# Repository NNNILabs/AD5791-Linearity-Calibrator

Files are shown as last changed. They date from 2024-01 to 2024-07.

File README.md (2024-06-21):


# AD5791 Linearity Calibrator

<p align="center">
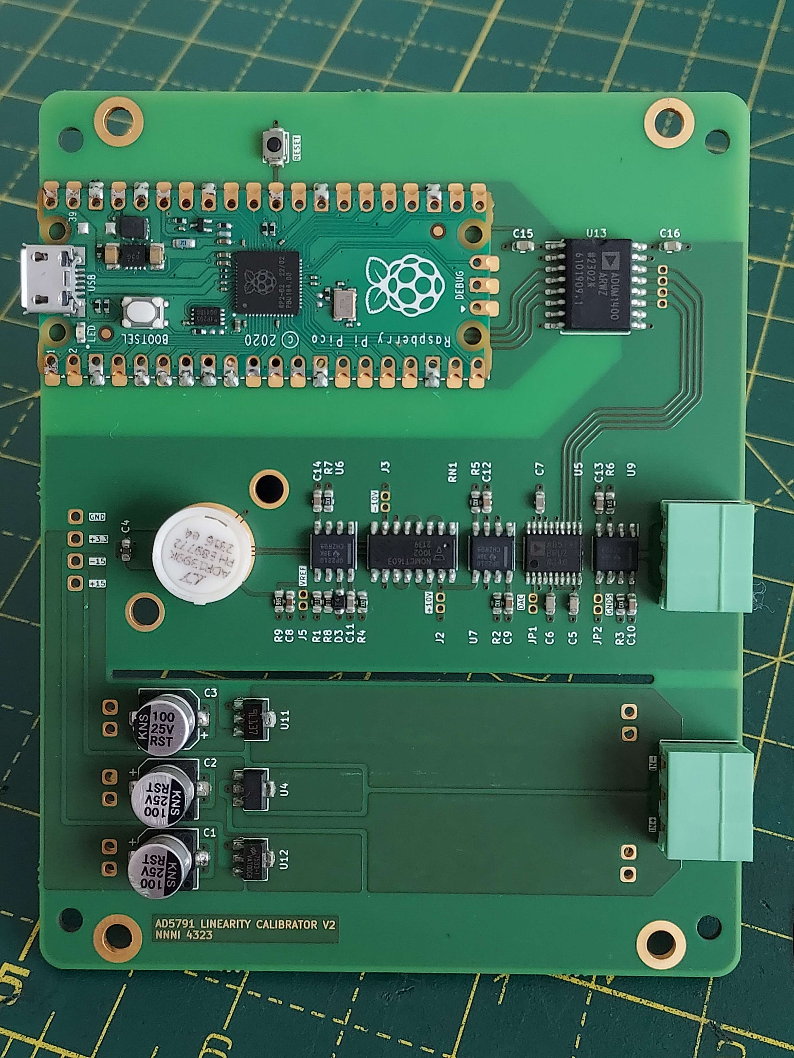
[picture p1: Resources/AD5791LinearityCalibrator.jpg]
  
</p>

## Introduction
Portable voltage, current and resistance standards exist and can be bought for a hole in your pocket, but linearity has exclusively been the domain of high-end bench multimeters. This project contains files for a linearity calibrator based around the AD5791BRUZ 20 bit DAC and a few assisting components. 
## Project Motivation
The gold standard for DMM linearity is the HP/Agilent/Keysight 3458A. This meter costs upwards of several thousand Euros and is out of reach for most people.
While the AD5791 is not even close in terms of absolute linearity, the fact that it can be bought for much less (around 100 Euros) and has decent long-term INL stability (0.19LSB) makes it a good choice for a linearity transfer standard.
## Usage
The C/C++ SDK for the Raspberry Pi Pico can be installed using the one-click installer found [here](https://github.com/raspberrypi/pico-setup/blob/master/pico_setup.sh). The SW folder is opened using 'Pico - Visual Studio Code', and built using the 'gcc-arm-none-eabi' tool. The build file (AD5791LinCal.uf2) can be uploaded to a connected Pico by using upload.bat after suitable configuration (see notes).  

Power is supplied through the 3.5mm terminal block with the labels 'IN+' and 'IN-'. +/-18V is an ideal nominal supply. The DAC board is connected to a computer through the Raspberry Pi Pico controller's micro USB port. Communicating with the DAC is possible through any serial terminal. The binary code representing the desired output voltage is typed in, and the enter key is pressed to update the DAC output. The buffered DAC output is available on the 3.5mm terminal block with the labels 'OUT+' and 'OUT-'. Raw DAC output is available on the 'DAC' test point.  
  
The DAC's transfer function is as follows:
```math
V_{OUT} = \frac{(V_{REFP} - V_{REFN}) D}{2^{20} - 1} + V_{REFN}
```
Where:  
V<sub>OUT</sub> is the desired output voltage  
V<sub>REFP</sub> is the positive reference voltage (in this case approximately 10.5V)  
V<sub>REFN</sub> is the negative reference voltage (in this case approximately -10.5V)  
D is the integer digital code (0 to 1048575)  
  
For example, 0 would result in V<sub>REFN</sub> on the output, 524288 would result in ~0V, and 1048575 would result in V<sub>REFP</sub>. Each step is therefore approximately 20uV.

### Linearity
An example of the AD5791 DAC board was constructed and linearity was measured against a HP3458A DMM. Pre-endpoint fit was used to process the raw data from the DMM to provide a linearity chart. The starting and ending points of the linearity run (in this case, 0 and 1032192) were measured first, and used to pre-calculate m and c values that are applied to the complete run that follows. This provides an indication of drift, and if its effect on the run was larger than the peak non-linearity, in which case the run can be discarded. In this example, the drift across all five runs was around 0.3ppm, corresponding to 3uV.

<p align="center">
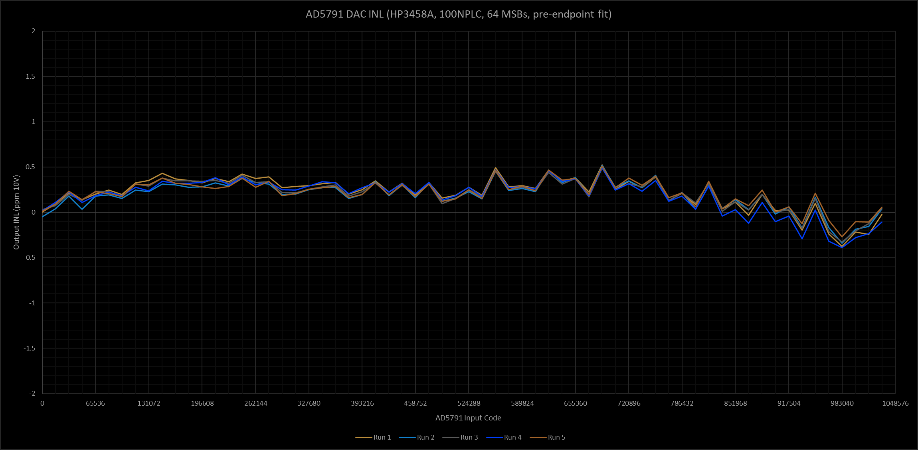
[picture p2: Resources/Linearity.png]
  
</p>

## List of Files
- Hardware: KiCAD schematic and PCB files, GERBER files, BOM
- Software: C/C++ code for the Raspberry Pi Pico, .uf2 file for direct upload, upload.bat upload assistant
- Resources: Images, AD5791 datasheet and ISSCC paper mirror
## Application Examples
### Determining Linearity of a DMM
Integral Non-Linearity (INL) describes how the input/output transfer function of a multimeter differs from the ideal straight line. Test methodology involves connecting a voltage source with a known linearity to the meter, and measuring meter readings at various points. Since the meter and source gains and offsets are not guaranteed to be the same, the source gain and offset has to be "normalized" to the meter gain and offset through a simple linear endpoint-fit method. Although some information at the endpoints is lost, it is most often the "shape" of the INL curve that is of interest. The data could possibly be used to derive a transfer function to further increase DAC/ADC linearity.
### Stable, Precise Voltage Source
Given the high resolution of the AD5791 (20 bits), fine voltage steps of 20uV can be achieved. This facilitates experiments that need ultrafine voltage steps. In some cases, the DAC, with its 1us settling time, can be used to generate precision waveforms through additional code modification (Wave table -> DMA -> PIO). 
## Notes
- By initializing GPIO 23 as an output and setting it high, the Raspberry Pi Pico's internal SMPS switches to PWM mode, where radiated EMI and output ripple is lower.
- PCB template is a modified version of [Mark's Protocard template](https://github.com/macaba/Nuts/tree/main/kicad-templates).
- [upload.bat](https://github.com/NNNILabs/AD5791-Linearity-Calibrator/blob/main/SW/upload.bat) was created by Utsuho, and faciliates hands-free upload to the Pico. The COM port the Pico is connected to and the drive letter are entered in lines 7 and 11 respectively. After the software is built, upload.bat is run from the terminal by doing '.\upload.bat' on Windows. The Pico enters boot mode and the .uf2 from the build folder is automatically uploaded. Make sure the COM port is not being accessed by other programs.
## Links
- [AD5791 Datasheet](https://github.com/NNNILabs/AD5791-Linearity-Calibrator/blob/main/Resources/AD5791%20Datasheet.pdf)
- [ISSCC Paper](https://github.com/NNNILabs/AD5791-Linearity-Calibrator/blob/main/Resources/AD5791%20ISSCC.pdf)
- [Reference voltage cap](https://www.printables.com/model/746207-voltage-reference-cap)

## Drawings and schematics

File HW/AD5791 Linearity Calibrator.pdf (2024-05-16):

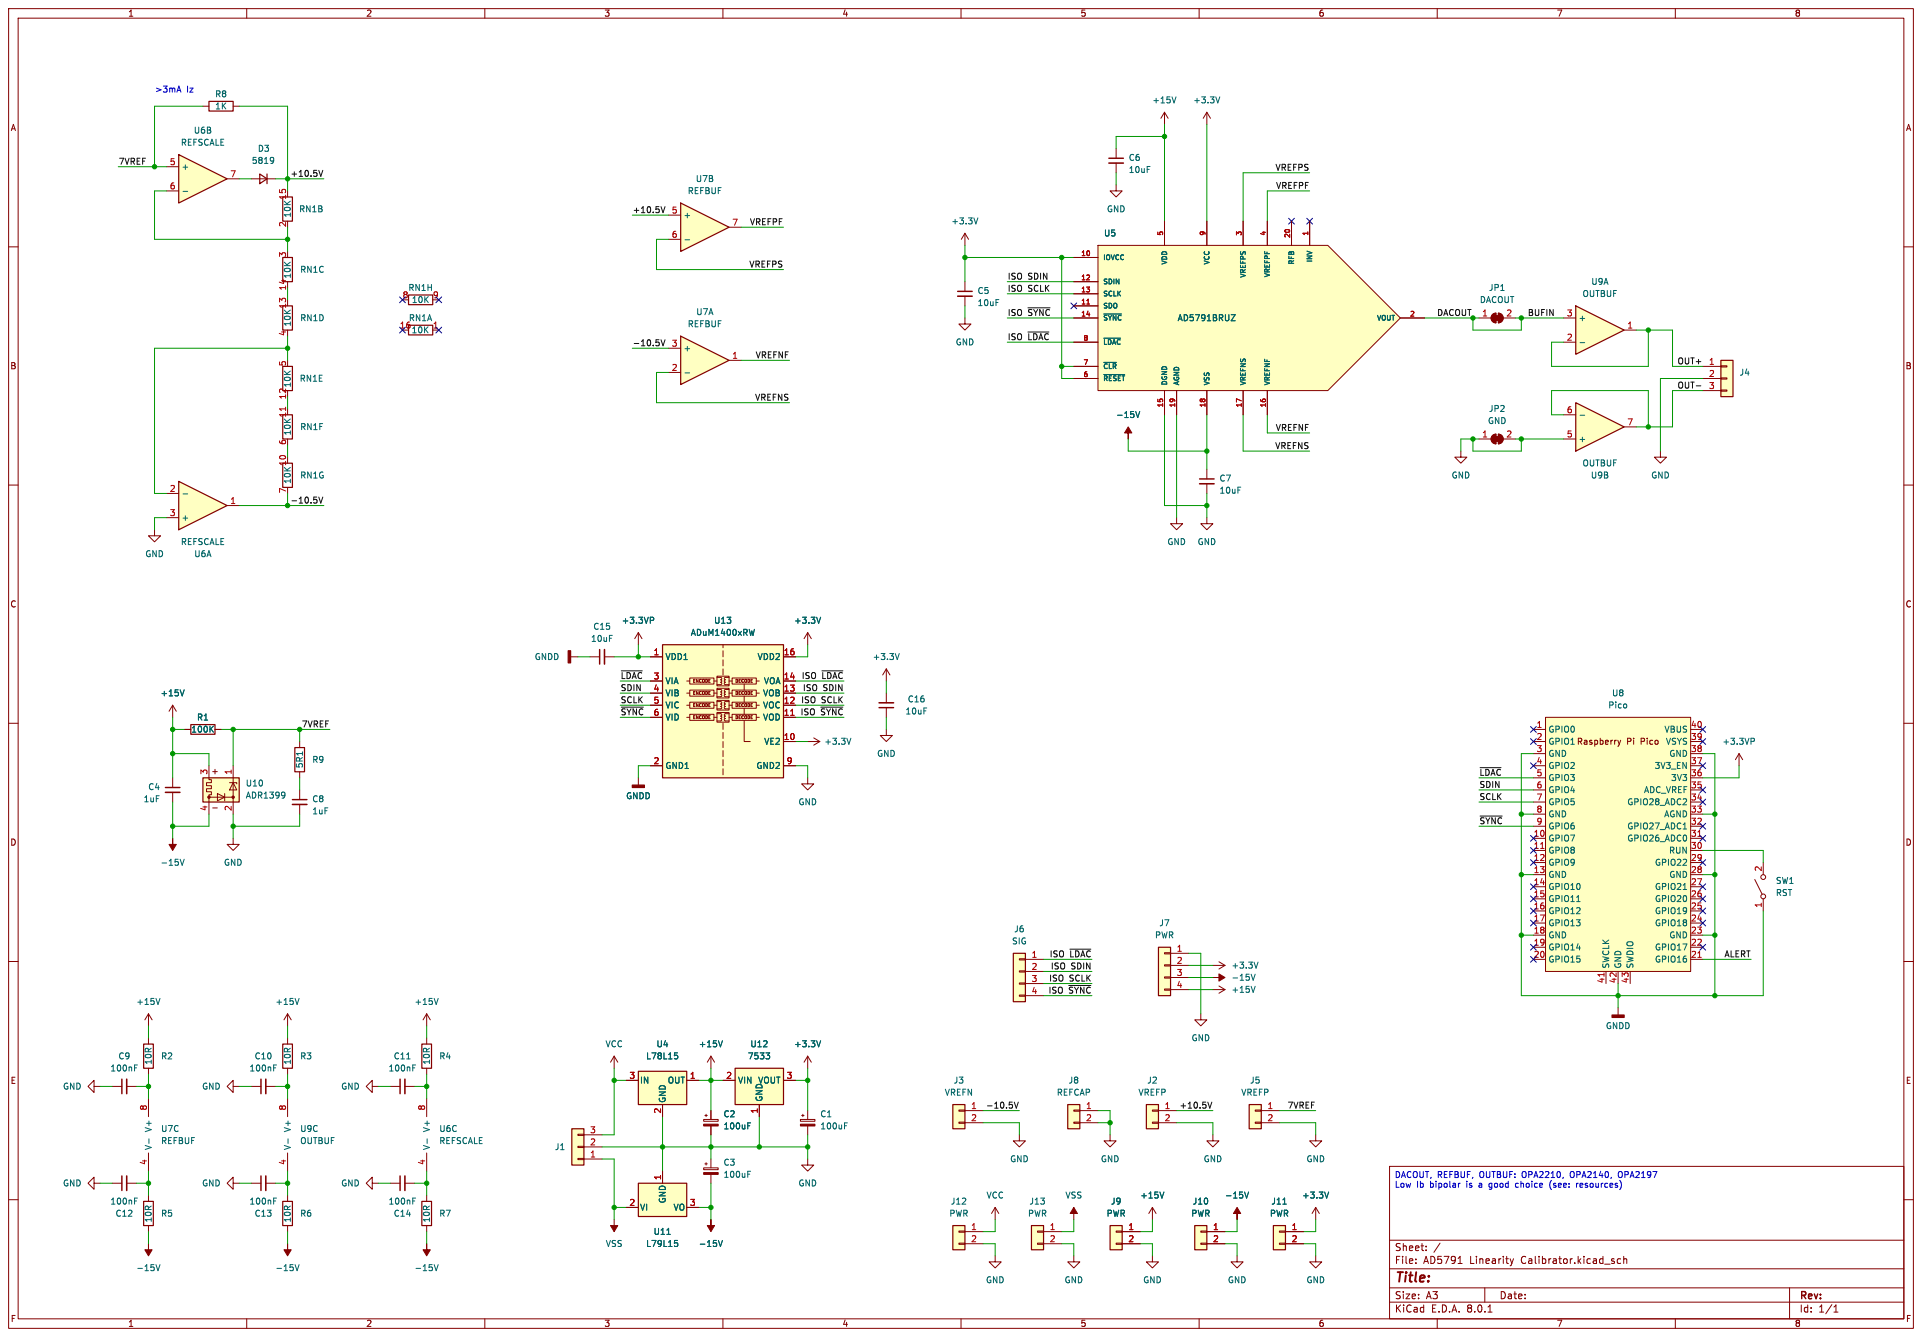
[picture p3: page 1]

5 ~{RESET} 6 ~{CLR} 7 ~{LDAC} 8 VCC U5 9 AD5791BRUZ

5 ~{RESET} 6 ~{CLR} 7 ~{LDAC} 8 VCC

DECODE DECODE

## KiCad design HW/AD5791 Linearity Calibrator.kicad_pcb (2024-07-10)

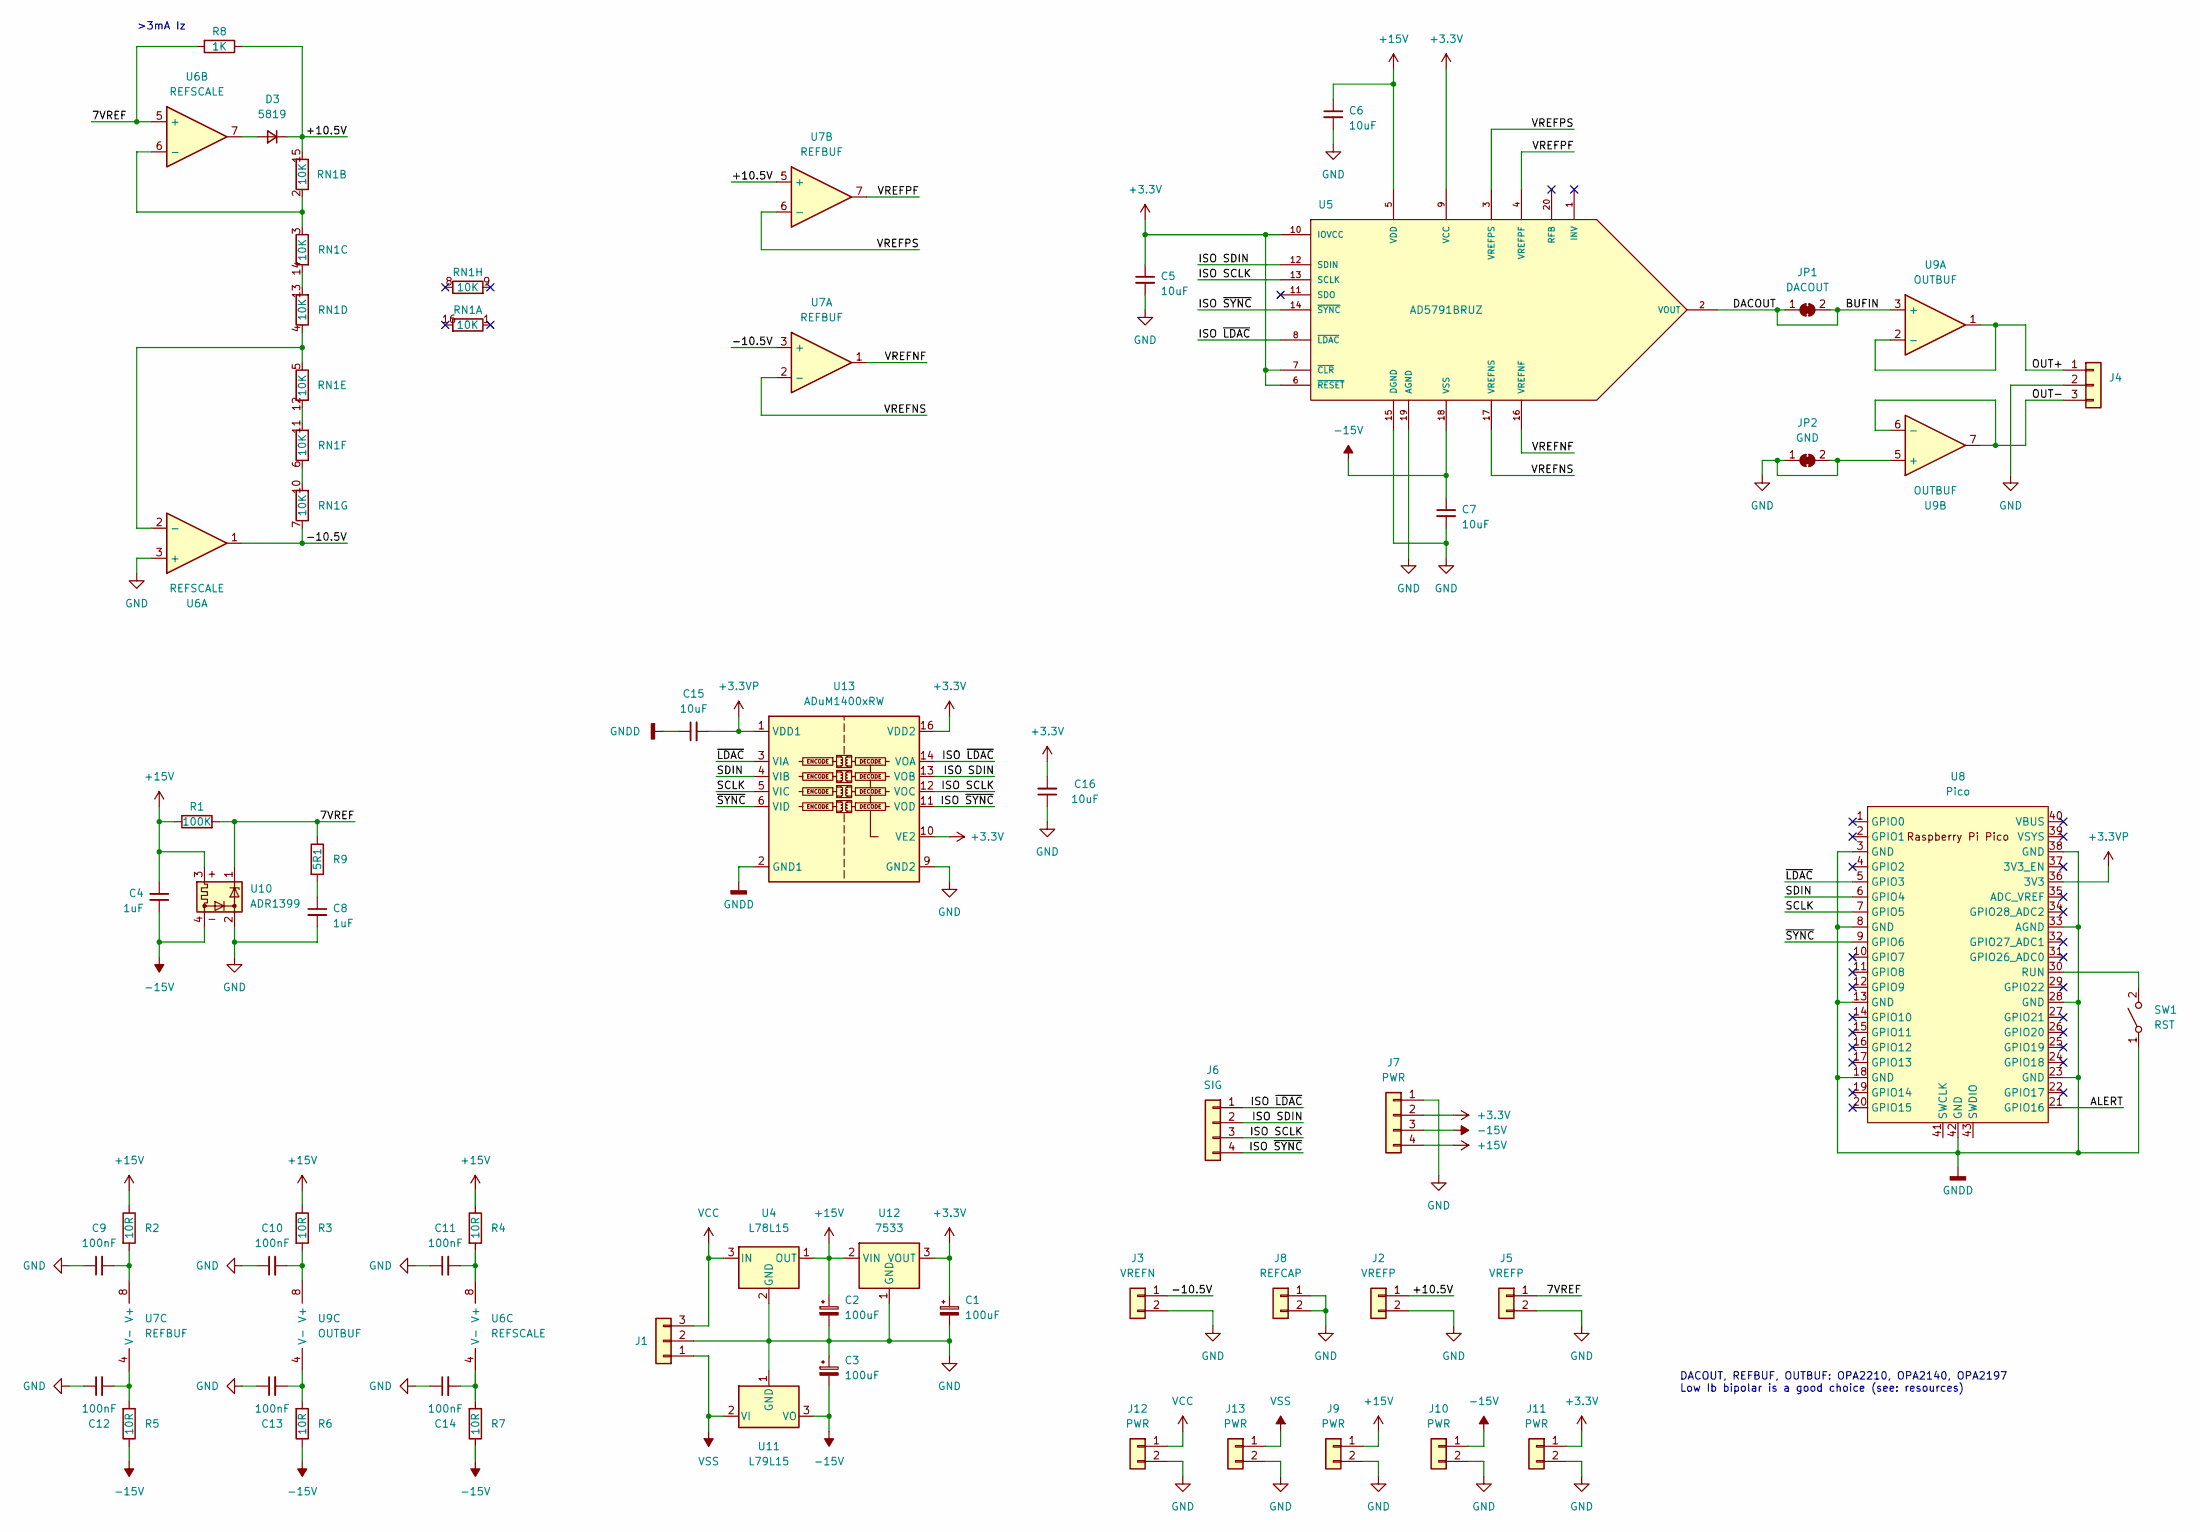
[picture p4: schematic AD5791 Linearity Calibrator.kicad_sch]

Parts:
C1, C2, C3: 100uF; CP_Elec_6.3x5.4
C4, C8: 1uF; C_0603_1608Metric
C5, C6, C7: 10uF; C_0603_1608Metric
C9, C10, C11, C12, C13, C14: 100nF; C_0603_1608Metric
C15, C16: 10uF; R_0603_1608Metric
D3: 5819; R_0603_1608Metric_Pad0.98x0.95mm_HandSolder
J1, J4: CTB93HD3
J2, J5: VREFP; PinHeader_1x02_P1.27mm_Vertical
J3: VREFN; PinHeader_1x02_P1.27mm_Vertical
J6: SIG; PinHeader_1x04_P1.27mm_Vertical
J7: PWR; PinHeader_1x04_P2.54mm_Vertical
J8: REFCAP; PinHeader_1x02_P1.27mm_Vertical
J9, J10, J11, J12, J13: PWR; PinHeader_1x02_P2.54mm_Vertical
JP1: DACOUT; PinHeader_1x02_P1.27mm_Vertical
JP2: GND; PinHeader_1x02_P1.27mm_Vertical
R1: 100K; R_0603_1608Metric
R2, R3, R4, R5, R6, R7: 10R; R_0603_1608Metric
R8: 1K; R_0603_1608Metric
R9: 5R1; R_0603_1608Metric
RN1: 10K; SOIC-16_3.9x9.9mm_P1.27mm
SW1: RST; SW_SPST_B3U-1000P
U4: L78L15; SOT-89-3
U5: AD5791BRUZ; SOP65P640X120-20N; MPN AD5791BRUZ
U6: REFSCALE; SOIC-8_3.9x4.9mm_P1.27mm
U7: REFBUF; SOIC-8_3.9x4.9mm_P1.27mm
U8: Pico; RPi_Pico_SMD_TH
U9: OUTBUF; SOIC-8_3.9x4.9mm_P1.27mm
U10: ADR1399; Analog_TO-46-4_ThermalShield
U11: L79L15; SOT-89-3
U12: 7533; SOT-89-3
U13: ADuM1400xRW; SOIC-16W_7.5x10.3mm_P1.27mm

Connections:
+3.3V: C1.1, C5.1, C16.2, J7.2, J11.1, U5.6 (~RESET), U5.7 (~CLR), U5.9 (VCC), U5.10 (IOVCC), U12.3 (VOUT), U13.10 (VE2), U13.16 (VDD2)
+3.3VP: C15.2, U8.36 (3V3), U13.1 (VDD1)
+15V: C2.1, C4.1, C6.1, J7.4, J9.1, R1.1, R2.1, R3.1, R4.1, U4.1 (OUT), U5.5 (VDD), U10.3, U12.2 (VIN)
-15V: C3.2, C4.2, C7.1, J7.3, J10.1, R5.1, R6.1, R7.1, U5.18 (VSS), U10.4, U11.3 (VO)
/7VREF: J5.1, R1.2, R8.2, R9.1, U6.5 (+), U10.1
/+10.5V: D3.1 (K), J2.1, R8.1, RN1.15 (R2.2), U7.5 (+)
/-10.5V: J3.1, RN1.7 (R7.1), U6.1, U7.3 (+)
/ALERT: U8.21 (GPIO16)
/BUFIN: JP1.1 (A), JP1.2 (B), U5.2 (VOUT), U9.3 (+)
/ISO SCLK: J6.3, U5.13 (SCLK), U13.12 (VOC)
/ISO SDIN: J6.2, U5.12 (SDIN), U13.13 (VOB)
/ISO ~LDAC: J6.1, U5.8 (~LDAC), U13.14 (VOA)
/ISO ~SYNC: J6.4, U5.14 (~SYNC), U13.11 (VOD)
/OUT+: J4.1, U9.1, U9.2 (-)
/OUT-: J4.3, U9.6 (-), U9.7
/SCLK: U8.7 (GPIO5), U13.5 (VIC)
/SDIN: U8.6 (GPIO4), U13.4 (VIB)
/VREFNF: U5.16 (VREFNF), U7.1
/VREFNS: U5.17 (VREFNS), U7.2 (-)
/VREFPF: U5.4 (VREFPF), U7.7
/VREFPS: U5.3 (VREFPS), U7.6 (-)
/~LDAC: U8.5 (GPIO3), U13.3 (VIA)
/~SYNC: U8.9 (GPIO6), U13.6 (VID)
GND: C1.2, C2.2, C3.1, C5.2, C6.2, C7.2, C8.2, C9.1, C10.1, C11.1, C12.1, C13.1, C14.1, C16.1, J1.2, J2.2, J3.2, J4.2, J5.2, J7.1, J8.1, J8.2, J9.2, J10.2, J11.2, J12.2, J13.2, JP2.1 (A), JP2.2 (B), U4.2 (GND), U5.15 (DGND), U5.19 (AGND), U6.3 (+), U9.5 (+), U10.2, U11.1 (GND), U12.1 (GND), U13.9 (GND2), U13.15 (GND2)
GNDD: C15.1, SW1.1 (A), U8.3 (GND), U8.8 (GND), U8.13 (GND), U8.18 (GND), U8.23 (GND), U8.28 (GND), U8.33 (AGND), U8.38 (GND), U8.42 (GND), U13.2 (GND1), U13.8 (GND1)
unnamed: C8.1, R9.2
unnamed: D3.2 (A), U6.7
unnamed: RN1.2 (R2.1), RN1.3 (R3.1), U6.6 (-)
unnamed: RN1.13 (R4.2), RN1.14 (R3.2)
unnamed: RN1.4 (R4.1), RN1.5 (R5.1), U6.2 (-)
unnamed: RN1.11 (R6.2), RN1.12 (R5.2)
unnamed: RN1.6 (R6.1), RN1.10 (R7.2)
unnamed: SW1.2 (B), U8.30 (RUN)
unnamed: C11.2, R4.2, U6.8 (V+)
unnamed: C14.2, R7.2, U6.4 (V-)
unnamed: C9.2, R2.2, U7.8 (V+)
unnamed: C12.2, R5.2, U7.4 (V-)
unnamed: C10.2, R3.2, U9.8 (V+)
unnamed: C13.2, R6.2, U9.4 (V-)
VCC: J1.3, J12.1, U4.3 (IN)
VSS: J1.1, J13.1, U11.2 (VI)

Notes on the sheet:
>3mA Iz
DACOUT, REFBUF, OUTBUF: OPA2210, OPA2140, OPA2197 Low Ib bipolar is a good choice (see: resources)

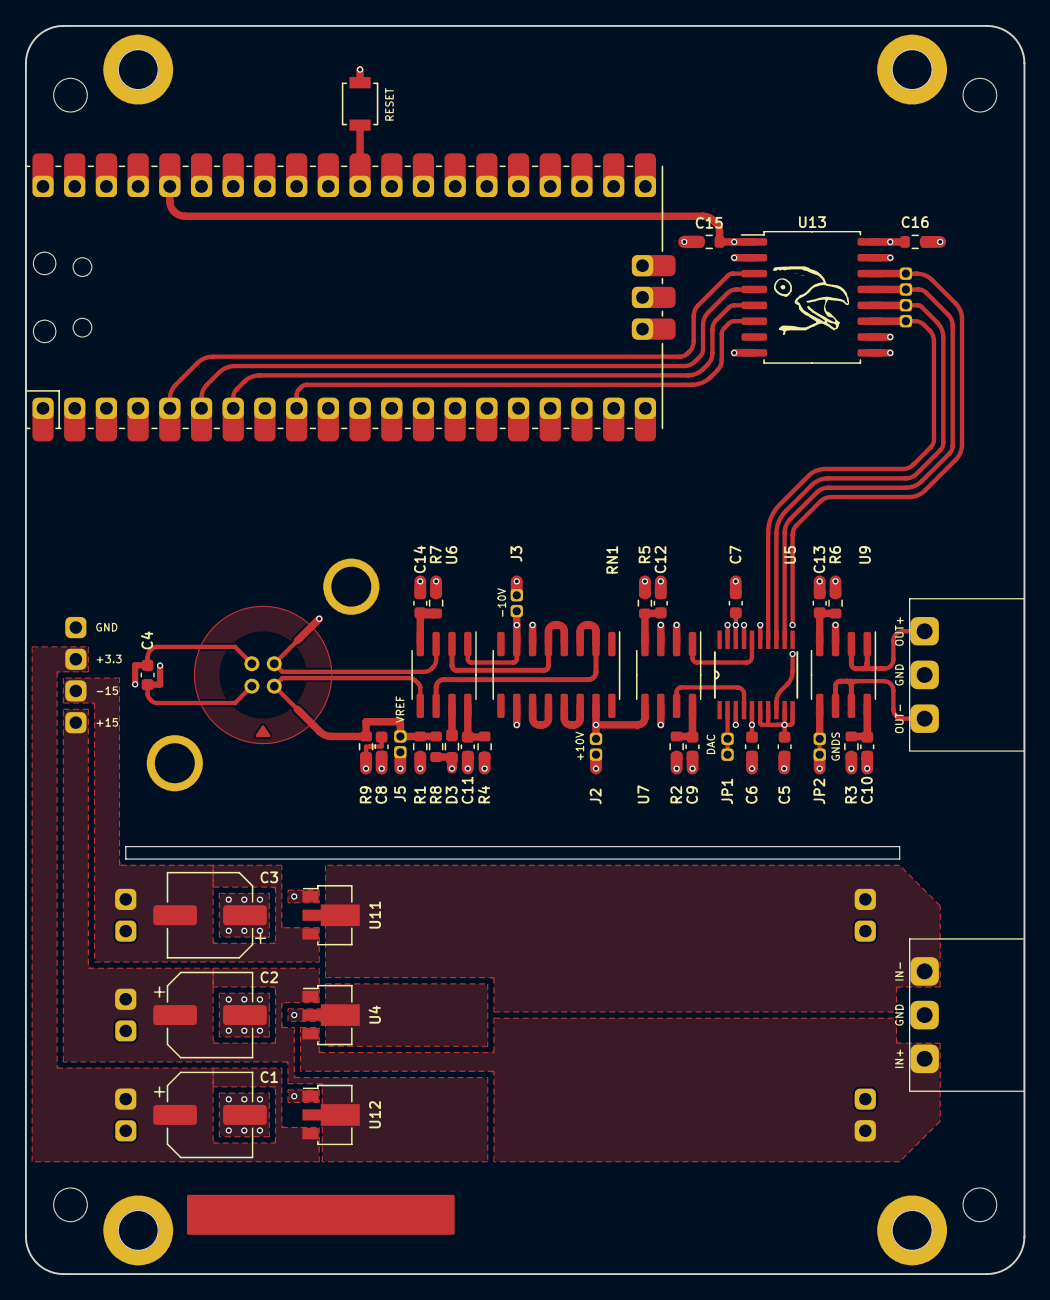
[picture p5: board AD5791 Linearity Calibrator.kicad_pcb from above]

Board: 4 copper layers, 80.0 x 100.0 mm, 53 parts (0 on the bottom side), 40 nets.

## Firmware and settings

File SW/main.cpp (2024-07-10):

#include <stdio.h>
#include <stdlib.h>

#include "pico/stdlib.h"
#include "pico/multicore.h"
#include "hardware/pio.h"
#include "hardware/clocks.h"

#include "output.pio.h"

#include "lib/i2c_slave.h"

// Register addresses
#define NOP   0b000
#define DAC   0b001
#define CTRL  0b010
#define CLR   0b011
#define SCTRL 0b100

// Read/write control bit
#define WRITE 0b0
#define READ  0b1

// Linearity compensation bits (see datasheet pg. 24: https://www.analog.com/media/en/technical-documentation/data-sheets/ad5791.pdf)
#define LINCOMP 0b1100

// Pinout
#define SDIN  4
#define SCLK  5
#define LDAC  3 // Inverting input
#define SYNC  6 // Inverting input

// V1 extra pins:
// #define SDO   3
// #define RESET 7 // Inverting input
// #define CLEAR 8 // Inverting input

// PIO global variables
PIO pio;
uint sm;
uint offset;

// Life indicator - use core 2 to blink built-in LED
void core2()
{
    gpio_init(25);
    gpio_set_dir(25, true);

    while (true)
    {
        gpio_put(25, 1);
        sleep_ms(50);
        gpio_put(25, 0);
        sleep_ms(4950);
    }
    
}

void dacWrite(uint32_t readwrite, uint32_t reg, uint32_t data)
{
    data = data % (0xFFFFF + 1);                                                      // Limit data value to 0xFFFFF max                              
    uint32_t packedData = packedData | (readwrite << 31) | (reg << 28) | (data << 8); // Pack read/write bit, register address bits and data bits
    pio_sm_put_blocking(pio, sm, packedData);                                         // Send packed data to PIO
    pio_sm_get_blocking(pio, sm);                                                     // SPI readback, to prevent stalling
}

int main() 
{
    stdio_init_all();
    i2c_init();
    
    set_sys_clock_khz(200000, true);
    multicore_launch_core1(core2);

    // Configure SMPS to operate in PWM mode
    gpio_init(23);
    gpio_set_dir(23, true);
    gpio_put(23, 1);
    
    // V1 extra pins:
    // gpio_pull_up(RESET); // Pull RESET pin high
    // gpio_pull_up(CLEAR); // Pull CLEAR pin high

    gpio_put(LDAC, 0);  // Set LDAC low to enable synchronous update

    // Initialize and configure PIO
    pio = pio0;
    sm = pio_claim_unused_sm(pio, true);
    offset = pio_add_program(pio, &output_program);
    output_program_init(pio, sm, offset, (float)10);
    pio_sm_set_enabled(pio, sm, true);

    // V1 extra pins:
    // gpio_put(RESET, 0);
    // sleep_ms(10);
    // gpio_put(RESET, 1);

    // Data: 00000000001100110010   RBUF       OPGND      DACTRI     BIN/2sC    SDODIS     LINCOMP
    uint32_t initData = initData | (1 << 1) | (0 << 2) | (0 << 3) | (1 << 4) | (0 << 5) | (LINCOMP << 6);

    dacWrite(WRITE, NOP, 0);         // Important - sets PIO pins to known state!
    dacWrite(WRITE, CTRL, initData); // Write initial configuration data to DAC
    dacWrite(WRITE, DAC, 524310);    // Start at zero upon power up, value from 'Test.xlsx'

    uint32_t count = 0;

    uint32_t requestedCode = 0;
    uint32_t newInput = 0;
    char inputBuffer[32] = {0};

    while(true)
    {
        // Uncomment for USB serial control
        // newInput = scanf("%s", &inputBuffer, 31);         // Read input from serial port
        // requestedCode = atoi(inputBuffer);                // Convert input to integer
        // inputBuffer[32] = {0};                            // Clear input buffer
        // dacWrite(WRITE, DAC, requestedCode);              // Write requested code to DAC
        // printf("Returned code: %d\n", requestedCode);

        // I2C peripheral control
        while(!regs.conversionStatus);
        sleep_ms(10);
        dacWrite(WRITE, DAC, regs.input);
        printf("Input register: %032b, DAC sollwert: %d\n", regs.input, (regs.input%(0xFFFFF+1)));
        regs.conversionStatus = 0;

    }

    return 0;
}

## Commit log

2023-07-04 PCB Layout - Halfway there
    [AD5791 Linearity Calibrator.kicad_pcb, AD5791 Linearity Calibrator.kicad_sch]
2023-07-06 Layout 1
    [AD5791 Linearity Calibrator.kicad_pcb, AD5791 Linearity Calibrator.kicad_sch]
2023-07-14 Finished Layout?
    [AD5791 Linearity Calibrator.kicad_pcb, AD5791 Linearity Calibrator.kicad_sch]
2023-07-17 Mark's Suggestions 1
    - Removed redundant reference buffers and modified reference buffer/scaler
    - Added passive compensation components around ADR1399
    - Added diode from output of 15V regulator to input of 3.3V regulator to prevent backfeeding when powered by USB
    - Removed temperature sensor module from PCB (add breakout headers later?)
    [AD5791 Linearity Calibrator.kicad_pcb, AD5791 Linearity Calibrator.kicad_sch]
2023-07-17 NOMC network
    [AD5791 Linearity Calibrator.kicad_sch]
2023-07-18 total creative block
    [AD5791 Linearity Calibrator.kicad_pcb, AD5791 Linearity Calibrator.kicad_sch]
2023-07-25 Backup commit
    [AD5791 Linearity Calibrator.kicad_pcb, AD5791 Linearity Calibrator.kicad_sch]
2023-07-25 Layout Revision 2
    [AD5791 Linearity Calibrator.kicad_pcb, AD5791 Linearity Calibrator.kicad_sch]
2023-07-28 layout, copper edges
    [AD5791 Linearity Calibrator.kicad_pcb, AD5791 Linearity Calibrator.kicad_sch]
2023-07-30 Layout Rev 2 Finished?
    [AD5791 Linearity Calibrator.kicad_pcb, AD5791 Linearity Calibrator.kicad_sch]
2023-07-30 Layout Rev 2 Finished (final touches)
    [AD5791 Linearity Calibrator.kicad_pcb]
2023-07-30 4 wire buffer, keepout under isolator traces
    [AD5791 Linearity Calibrator.kicad_pcb, AD5791 Linearity Calibrator.kicad_sch]
2023-07-30 Layout Rev 3
    [AD5791 Linearity Calibrator.kicad_pcb, AD5791 Linearity Calibrator.kicad_sch]
2023-07-30 added blank notes space
    [AD5791 Linearity Calibrator.kicad_pcb]
2023-07-30 blank space v2
    [AD5791 Linearity Calibrator.kicad_pcb]
2023-07-30 star ground added
    [AD5791 Linearity Calibrator.kicad_pcb, AD5791 Linearity Calibrator.kicad_sch]
2023-07-31 Widened slots for Aisler
    [AD5791 Linearity Calibrator.kicad_pcb]
2023-07-31 Layout Rev 4
    [AD5791 Linearity Calibrator.kicad_pcb, AD5791 Linearity Calibrator.kicad_sch, bom.csv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]
2023-09-21 post-assembly touch ups
    - ground coupling jumper now shorted by default
    - software files updated with pinout
    [AD5791 Linearity Calibrator.kicad_pcb, AD5791 Linearity Calibrator.kicad_sch, bom.csv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]
2023-09-23 working code
    code shows the correct waveforms to output to the DAC
    [AD5791 Linearity Calibrator.kicad_pcb]
2023-09-24 added setup code
    [AD5791 Linearity Calibrator.kicad_pcb]
2023-09-25 added serial interface
    [AD5791 Linearity Calibrator.kicad_pcb]
2023-09-26 added V2 files
    [AD5791 Linearity Calibrator.kicad_pcb, AD5791 Linearity Calibrator.kicad_sch]
2023-10-04 finalized schematics for v2
    [AD5791 Linearity Calibrator.kicad_pcb, AD5791 Linearity Calibrator.kicad_sch]
2023-10-11 updated v2 PCB files
    finalized layout?
    [AD5791 Linearity Calibrator.kicad_pcb, AD5791 Linearity Calibrator.kicad_sch]
2023-10-12 updated v2 layout
    added isolator, artwork, finalized placement
    [AD5791 Linearity Calibrator.kicad_pcb, AD5791 Linearity Calibrator.kicad_sch]
2023-10-12 updated files
    [AD5791 Linearity Calibrator.kicad_pcb, AD5791 Linearity Calibrator.kicad_sch]
2023-10-14 updated layout
    [AD5791 Linearity Calibrator.kicad_pcb, AD5791 Linearity Calibrator.kicad_sch]
2023-10-22 Finished V2 layout (rev1)
    [AD5791 Linearity Calibrator.kicad_pcb]
2023-10-22 rearranged files
    [AD5791 Linearity Calibrator.kicad_pcb, AD5791 Linearity Calibrator.kicad_sch]
2023-10-25 layout touch up
    [AD5791 Linearity Calibrator.kicad_pcb]
2023-10-25 fixed missing connection
    [AD5791 Linearity Calibrator.kicad_pcb]
2023-10-25 further finishing touches
    [AD5791 Linearity Calibrator.kicad_pcb, AD5791 Linearity Calibrator.kicad_sch]
2023-10-25 finishing touches
    [AD5791 Linearity Calibrator.kicad_pcb]
2023-10-26 added input silkscreen designator
    [AD5791 Linearity Calibrator.kicad_pcb]
2023-11-17 added files
    - added pico library zip
    - updated upload.bat
2024-01-17 minor touch-ups
    - Added tab designator to thermal isolation ring for easy xxxx399 reference placement
    - Moved copyright text to In1.Cu for better front side visibility
    [AD5791 Linearity Calibrator.kicad_pcb]
2024-01-18 Update AD5791 Linearity Calibrator.kicad_sch
    added annotations for specific parts choices (op-amps)
    [AD5791 Linearity Calibrator.kicad_sch]
2024-01-19 added net and silkscreen labels
    [AD5791 Linearity Calibrator.kicad_pcb, AD5791 Linearity Calibrator.kicad_sch]
2024-01-21 fixed small PCB mistake
    [AD5791 Linearity Calibrator.kicad_pcb]
2024-01-25 minor changes in schem and pcb
    [AD5791 Linearity Calibrator.kicad_pcb, AD5791 Linearity Calibrator.kicad_sch]
2024-05-16 added linearity chart
    [AD5791 Linearity Calibrator.kicad_sch]
2024-07-10 latest files
    [AD5791 Linearity Calibrator.kicad_pcb]

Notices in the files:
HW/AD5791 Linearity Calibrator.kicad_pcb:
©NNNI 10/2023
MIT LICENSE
